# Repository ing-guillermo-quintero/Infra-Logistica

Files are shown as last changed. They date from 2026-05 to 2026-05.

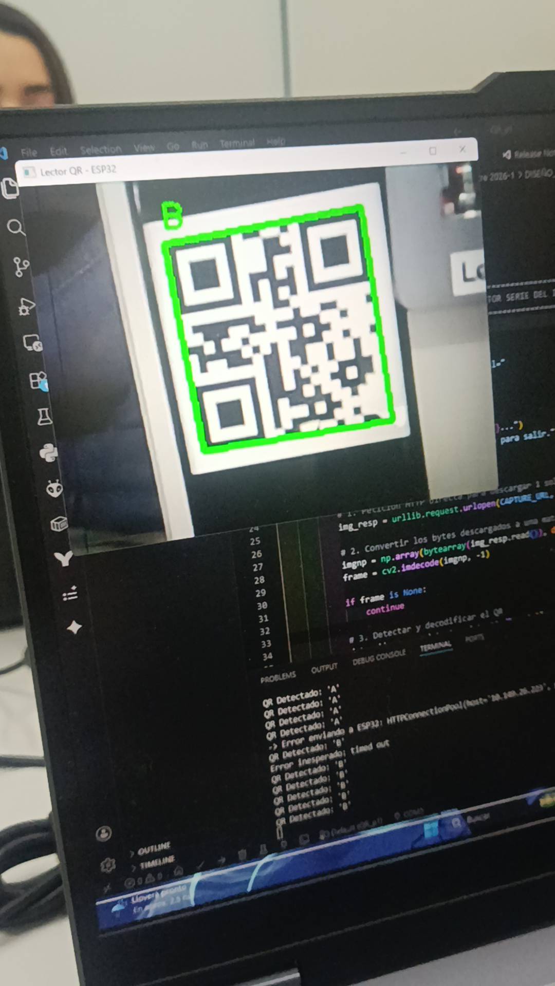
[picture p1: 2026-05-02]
Pruebas_unitarias_Sistema_Lectura_QR/IMG_1.jpg

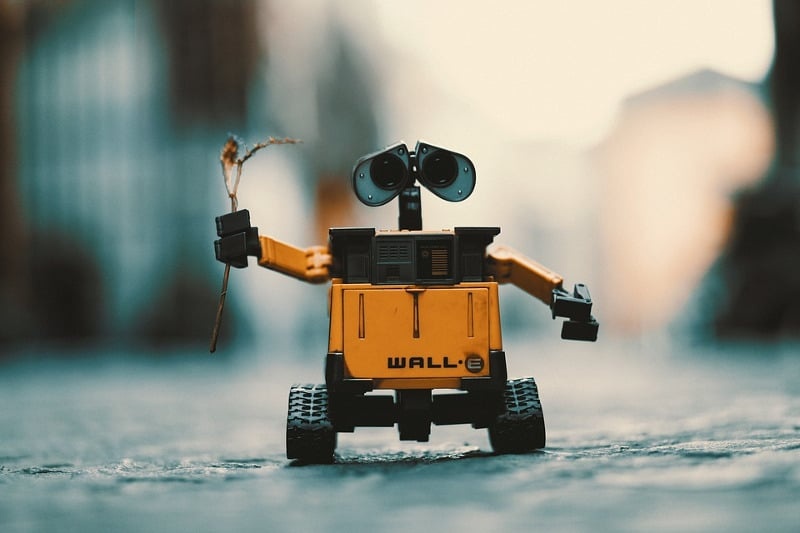
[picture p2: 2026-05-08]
Sistema_Lectura_QR/Lector_QR_V2/imagenes/wall-e.jpg

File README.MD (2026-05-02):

# 📦 Proyecto de Infraestructura y Logística

## 📖 Descripción General
Este repositorio contiene la documentación técnica, diseños mecánicos, planos generales y ruteo electrónico de un sistema de infraestructura logística automatizada.

El proyecto integra componentes mecánicos (estructura y banda transportadora), diseño eléctrico-electrónico y pruebas del sistema de lectura QR, permitiendo la identificación y transporte eficiente de elementos dentro del sistema.

---

## 🗂️ Estructura del Proyecto
.
├── CADs/
│ ├── Infraestructura.STEP
│ └── Banda_transportadora.STEP
│
├── Diseño_Plano_General/
│ └── (Planos generales del sistema)
│
├── Firmware_Infraestructura/
│
├── Pruebas_unitarias_Sistema_Lectura_QR/
│
├── Ruteo_eléctrico-electrónico/
│ └── (Archivo Proteus - conexiones electrónicas)
│
└── Sistema_Lectura_QR/

---

## 📁 Descripción de Carpetas

### 🔧 CADs/
Contiene los modelos 3D del sistema en formato `.STEP`, fundamentales para el diseño mecánico:

- **Infraestructura.STEP**  
  Representa la estructura completa del sistema logístico.

- **Banda_transportadora.STEP**  
  Modelo detallado de la banda transportadora, incluyendo soportes y sistema de desplazamiento.

Estos archivos permiten:
- Visualización tridimensional
- Validación dimensional
- Preparación para fabricación

---

### 📐 Diseño_Plano_General/
Incluye los planos generales del sistema, donde se define:

- Distribución de la infraestructura
- Ubicación de los módulos
- Relación entre componentes mecánicos

Sirve como referencia principal para el montaje físico del sistema.

---

### ⚙️ Firmware_Infraestructura/
Contiene el desarrollo del firmware encargado del control del sistema:

- Lógica de operación
- Control de actuadores
- Lectura de sensores
- Integración con el sistema de lectura QR

---

### 🧪 Pruebas_unitarias_Sistema_Lectura_QR/
Incluye pruebas orientadas a validar el funcionamiento del sistema de lectura QR:

- Precisión de lectura
- Tiempo de respuesta
- Integración con el sistema general

---

### 🔌 Ruteo_eléctrico-electrónico/
Contiene el diseño electrónico del sistema:

- Archivo de simulación en **Proteus**
- Conexiones del controlador
- Integración de sensores

Permite:
- Simulación del circuito
- Verificación de conexiones
- Validación del diseño electrónico

---

### 📡 Sistema_Lectura_QR/
Módulo encargado de la lectura e interpretación de códigos QR:

- Captura de datos
- Procesamiento de información
- Comunicación con el sistema principal

---

## 🧩 Componentes del Sistema

- Estructura mecánica modular
- Banda transportadora
- Sensores electrónicos
- Controlador principal
- Sistema de lectura QR

---

## 🎯 Objetivo del Proyecto

Desarrollar un sistema automatizado de logística que permita:

- Transporte eficiente de elementos
- Identificación mediante códigos QR
- Integración mecánica y electrónica
- Escalabilidad del sistema

---

## 🛠️ Herramientas Utilizadas

- Software CAD (archivos `.STEP`)
- Proteus (simulación electrónica)
- Sistemas embebidos (controlador)
- Herramientas de desarrollo de firmware

---

## 📌 Notas

- Los archivos `.STEP` pueden visualizarse en herramientas como SolidWorks, Fusion 360 o FreeCAD.
- El archivo de Proteus requiere el entorno instalado para su simulación.
- Este repositorio está orientado tanto a documentación técnica como a desarrollo del sistema.

---

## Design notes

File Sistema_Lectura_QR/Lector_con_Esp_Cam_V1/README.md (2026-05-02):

# Sistema de Visión y Detección QR con ESP32

Este proyecto contiene un script en Python (`Prueba1Webservice.py`) que actúa como cliente para un módulo ESP32 equipado con cámara. El sistema captura imágenes enviadas por el ESP32, procesa las imágenes para detectar códigos QR y envía la información decodificada de vuelta al microcontrolador.

La arquitectura está basada en un modelo **Cliente-Servidor** a través de red local (Wi-Fi), distribuido en dos componentes principales:

1. **Servidor (Edge Device - ESP32):**
   - El ESP32 actúa como un servidor web HTTP.
   - **Cámara:** Se encarga de capturar el entorno de manera continua.
   - **Endpoint `/capture`:** Proveedor de imágenes. Al hacer una petición GET, responde con el frame actual de la cámara (foto en formato binario/JPEG).
   - **Endpoint `/serial?val=<datos>`:** Receptor de comandos. Permite recibir cadenas de texto (en este caso, la información del QR) y procesarlas o mostrarlas por el monitor serie del microcontrolador.

2. **Cliente (Procesamiento de Visión - PC con Python):**
   - El script de Python realiza el procesamiento pesado que el ESP32 no puede o le costaría mucho hacer (Computer Vision).
   - Realiza _polling_ constante (peticiones HTTP directas) al endpoint `/capture` para simular un stream de video en tiempo real.
   - Decodifica la imagen utilizando `numpy` y `OpenCV`.
   - Utiliza `cv2.QRCodeDetector()` para analizar la imagen y buscar códigos QR.
   - Si detecta un código QR, envía el dato obtenido de regreso al ESP32 a través del endpoint `/serial`.

## Flujo de Funcionamiento del Código (`Prueba1Webservice.py`)

1. **Configuración y Conexión:**
   Se define la dirección IP del ESP32 (`ESP32_IP = "192.168.2.98"`) en la red local. A partir de ella se construyen las URLs para la captura de imágenes (`CAPTURE_URL`) y el envío de datos (`SERIAL_URL`).

2. **Bucle de Captura:**
   Entra en un ciclo infinito `while True` donde:
   - Se solicita la imagen al ESP32 mediante `urllib.request.urlopen`.
   - Los bytes recibidos se transforman en un arreglo (array) de `numpy`.
   - Se decodifica la imagen a un formato matricial (frame) compatible con OpenCV (`cv2.imdecode`).

3. **Detección y Decodificación del QR:**
   - El detector analiza el frame. Si encuentra un código QR, extrae las coordenadas (`bbox`) y la información en texto (`data`).
   - El código dibuja un recuadro verde alrededor del QR detectado utilizando `cv2.polylines`.

4. **Retorno de Información (Feedback) al ESP32:**
   - Se implementa una lógica de anti-spam (temporizador de 2 segundos mediante `time.time()`) para no sobrecargar de peticiones al ESP32 si el mismo QR permanece frente a la cámara.
   - Si hay una nueva lectura (o pasaron más de 2 segundos), la información es mostrada en la terminal local y enviada de vuelta al ESP32 utilizando la librería `requests` (`requests.get(SERIAL_URL + data)`).

5. **Visualización en PC:**
   - Para mejorar la visibilidad (dado que la resolución base parece ser baja, por ejemplo, 240p), el frame es redimensionado (`cv2.resize` a 640x480).
   - El flujo de video modificado (con los recuadros verdes y el texto) se muestra en una ventana interactiva (`cv2.imshow`).
   - El bucle puede detenerse en cualquier momento presionando la tecla **`q`**.

## Requisitos y Dependencias

Para ejecutar este script, es necesario contar con Python instalado y las siguientes librerías:

- `opencv-python` (cv2)
- `numpy`
- `requests`
- `urllib` (Librería estándar de Python)
- `time` (Librería estándar de Python)

Para instalar las dependencias externas (si no están instaladas), puedes ejecutar:

```bash
pip install opencv-python numpy requests
```

## Instrucciones de Uso

1. Cargar el firmware correspondiente en el ESP32 que levante el servidor web de la cámara y los endpoints (`/capture`, `/serial`).
2. Abrir el Monitor Serie del IDE de Arduino (u otro de preferencia) para observar la dirección IP asignada al ESP32.
3. Modificar la variable `ESP32_IP` en la **línea 10** del archivo `Prueba1Webservice.py` con la IP obtenida.
4. Ejecutar el script:
   ```bash
   python Prueba1Webservice.py
   ```
5. Colocar un código QR frente a la cámara del ESP32. Se podrá ver en la ventana del PC el recuadro de reconocimiento y el ESP32 recibirá la información.
6. Presionar la tecla `q` en la ventana del video para cerrar el programa.

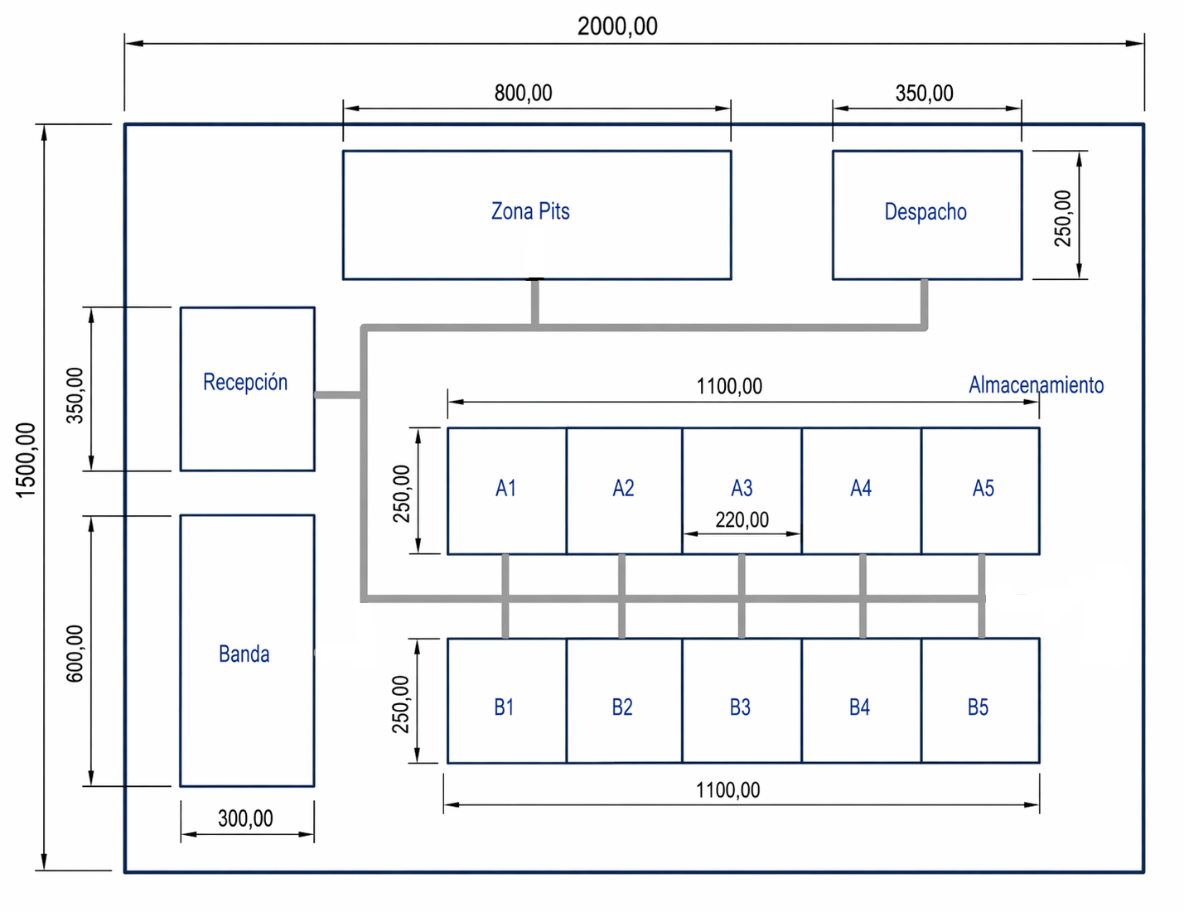
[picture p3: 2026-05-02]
Diseño_Plano_General/Diseno.png

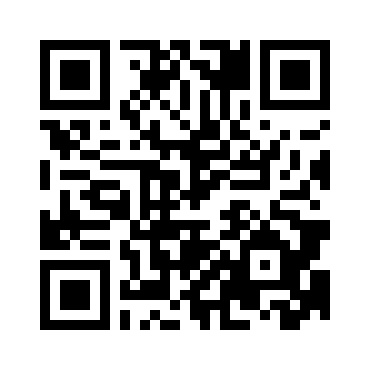
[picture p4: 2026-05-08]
Sistema_Lectura_QR/Lector_QR_V2/codigos_qr/QR_wall-e.png

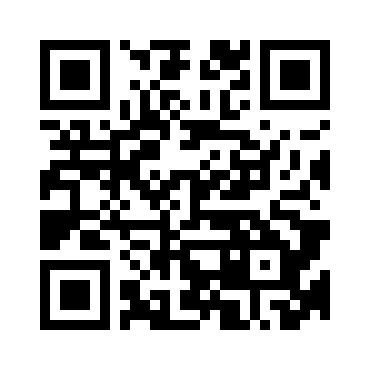
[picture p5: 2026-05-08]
Sistema_Lectura_QR/Lector_QR_V2/codigos_qr/QR_rosas.png

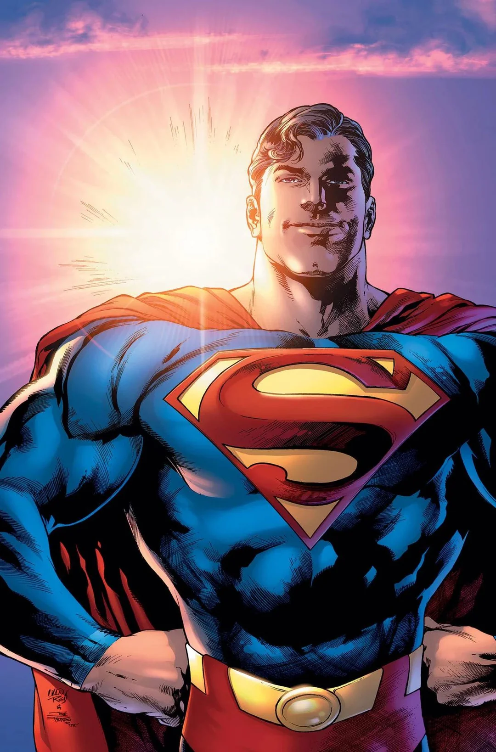
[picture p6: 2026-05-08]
Sistema_Lectura_QR/Lector_QR_V2/imagenes/superman.webp

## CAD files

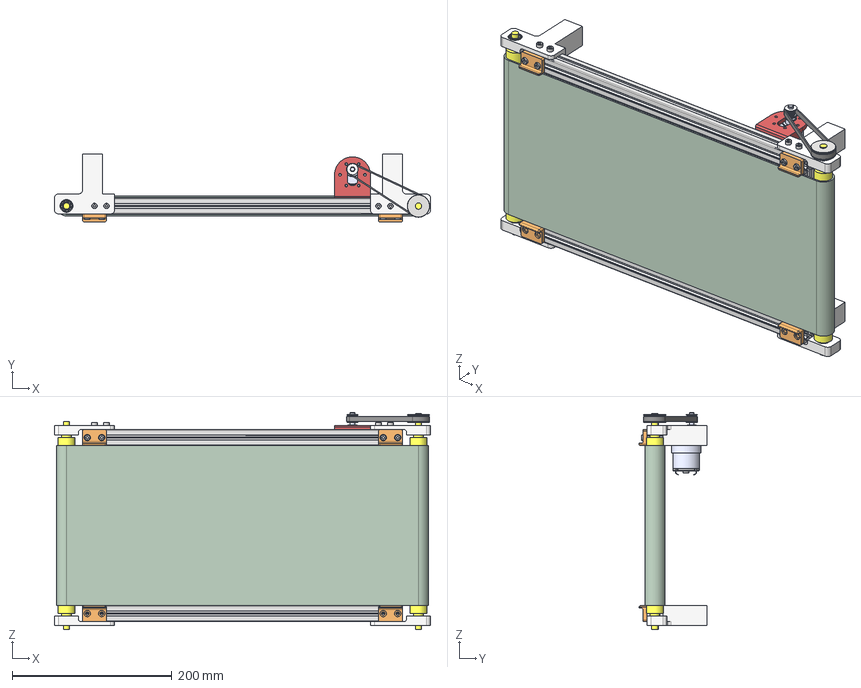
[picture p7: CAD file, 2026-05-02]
CADs/Banda_transportadora.stp
470.0 x 85.2 x 271.5 mm
tslot-20x20-1
tslot-20x20-1_MIR
tslot-20x20-2 x 3
SNSD20x20 x 3
SNSD20x20_MIR x 3
MM-JGB37 v4_MIR_MIR
JGB37-520_MIR_MIR
lato
cilindro_01
piastra_laterale_cilindro
GT2 16 Teeth Free Pulley
GT2 Timing Pulley T40 small
%3% BS 290 - SKF 618/8 x 6
piastra_laterale_cilindro_MIR
cilindro_01_MIR
piastra_laterale_cilindro_MIR1
piastra_laterale_cilindro_MIR_MIR
cinghia
nastro
blocco_nastro
blocco_nastro_MIR
blocco_nastro_MIR1
blocco_nastro_MIR_MIR
AS 1420 - 1973 - M4 x 8 x 8
AS 1420 - 1973 - M4 x 20 x 2

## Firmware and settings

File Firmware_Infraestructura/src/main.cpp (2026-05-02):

#include <Arduino.h>
#include <WiFi.h>
#include <PubSubClient.h>

// ==========================================
// CONFIGURACIÓN WIFI Y MQTT
// ==========================================
const char* ssid = "TU_RED_WIFI";
const char* password = "TU_PASSWORD";
const char* mqtt_server = "IP_DE_TU_BROKER";
const int mqtt_port = 1883;

WiFiClient espClient;
PubSubClient client(espClient);

// Mutex para proteger la librería MQTT entre los dos núcleos
SemaphoreHandle_t mqttMutex;

// ==========================================
// DEFINICIÓN DE PINES (ESP32-S3)
// ==========================================
// Zona de Recolección - Motor
const int PIN_ENA = 4;
const int PIN_IN1 = 5;
const int PIN_IN2 = 6;

// Zona de Recolección - Sensores IR
const int PIN_SENSOR_IR1 = 7;
const int PIN_SENSOR_IR2 = 8;

// Zona de Almacenamiento - Registro de Desplazamiento
const int LATCH_PIN = 9;
const int CLOCK_PIN = 10;
const int DATA_PIN  = 11;

// Zona de Despacho
const int PIN_SENSOR_DESPACHO = 12;

// ==========================================
// VARIABLES DE ESTADO
// ==========================================
enum EstadoBanda { BANDA_CORRIENDO, ESPERANDO_PARADA, CAJA_LISTA };
EstadoBanda estadoActualBanda = BANDA_CORRIENDO;

unsigned long tiempoDeteccionIR1 = 0;
const unsigned long TIEMPO_ESPERA_PARADA = 2000;
unsigned long ultimoEnvioSensores = 0;
const unsigned long INTERVALO_ENVIO_SENSORES = 1000;
int estadoAnteriorDespacho = -1;

// ==========================================
// PROTOTIPOS DE FUNCIONES (Requerido en C++/PlatformIO)
// ==========================================
void setup_wifi();
void reconnect();
void arrancarBanda();
void detenerBanda();
uint16_t leerRegistroDesplazamiento();
void TareaSensoresYRed(void *pvParameters);
void TareaRecepcionYDespacho(void *pvParameters);

// ==========================================
// FUNCIONES DE RED
// ==========================================
void setup_wifi() {
  vTaskDelay(pdMS_TO_TICKS(10));
  Serial.println("\nConectando a WiFi...");
  WiFi.begin(ssid, password);
  while (WiFi.status() != WL_CONNECTED) {
    vTaskDelay(pdMS_TO_TICKS(500));
    Serial.print(".");
  }
  Serial.println("\nWiFi conectado.");
}

void reconnect() {
  while (!client.connected() && WiFi.status() == WL_CONNECTED) {
    Serial.print("Intentando conexión MQTT...");
    if (client.connect("ESP32_S3_Almacen")) {
      Serial.println("Conectado al broker");
    } else {
      Serial.print("Fallo, rc=");
      Serial.print(client.state());
      Serial.println(" reintentando en 5 segundos");
      vTaskDelay(pdMS_TO_TICKS(5000));
    }
  }
}

// ==========================================
// FUNCIONES DE CONTROL FÍSICO
// ==========================================
void arrancarBanda() {
  digitalWrite(PIN_IN1, HIGH);
  digitalWrite(PIN_IN2, LOW);
  analogWrite(PIN_ENA, 200);
}

void detenerBanda() {
  digitalWrite(PIN_IN1, LOW);
  digitalWrite(PIN_IN2, LOW);
  analogWrite(PIN_ENA, 0);
}

uint16_t leerRegistroDesplazamiento() {
  digitalWrite(LATCH_PIN, LOW);
  delayMicroseconds(5);
  digitalWrite(LATCH_PIN, HIGH);
  
  uint16_t valores = 0;
  for (int i = 0; i < 16; i++) {
    int bitLeido = digitalRead(DATA_PIN);
    valores |= (bitLeido << (15 - i));
    digitalWrite(CLOCK_PIN, HIGH);
    delayMicroseconds(5);
    digitalWrite(CLOCK_PIN, LOW);
  }
  return valores;
}

// ==========================================
// TAREAS DE LOS NÚCLEOS (FreeRTOS)
// ==========================================

// --- NÚCLEO 0: Sensores de Almacenamiento y Red MQTT ---
void TareaSensoresYRed(void *pvParameters) {
  setup_wifi();
  client.setServer(mqtt_server, mqtt_port);

  for (;;) {
    if (xSemaphoreTake(mqttMutex, portMAX_DELAY) == pdTRUE) {
      if (!client.connected()) {
        reconnect();
      }
      client.loop();
      xSemaphoreGive(mqttMutex);
    }

    if (millis() - ultimoEnvioSensores >= INTERVALO_ENVIO_SENSORES) {
      ultimoEnvioSensores = millis();
      uint16_t sensoresAlmacen = leerRegistroDesplazamiento();
      
      String payload = "{";
      payload += "\"FilaA\": [";
      for(int i=0; i<5; i++) {
        payload += String(bitRead(sensoresAlmacen, i));
        if(i < 4) payload += ",";
      }
      payload += "], \"FilaB\": [";
      for(int i=0; i<5; i++) {
        payload += String(bitRead(sensoresAlmacen, i + 8));
        if(i < 4) payload += ",";
      }
      payload += "]}";
      
      if (xSemaphoreTake(mqttMutex, portMAX_DELAY) == pdTRUE) {
        client.publish("almacen/almacenamiento/celdas", payload.c_str());
        xSemaphoreGive(mqttMutex);
      }
    }
    vTaskDelay(pdMS_TO_TICKS(10)); 
  }
}

// --- NÚCLEO 1: Recepción (Banda) y Despacho ---
void TareaRecepcionYDespacho(void *pvParameters) {
  arrancarBanda();

  for (;;) {
    bool deteccionIR1 = (digitalRead(PIN_SENSOR_IR1) == LOW);
    bool deteccionIR2 = (digitalRead(PIN_SENSOR_IR2) == LOW);

    switch (estadoActualBanda) {
      case BANDA_CORRIENDO:
        if (deteccionIR1) {
          tiempoDeteccionIR1 = millis();
          estadoActualBanda = ESPERANDO_PARADA;
        }
        break;

      case ESPERANDO_PARADA:
        if (millis() - tiempoDeteccionIR1 >= TIEMPO_ESPERA_PARADA) {
          detenerBanda();
          if (xSemaphoreTake(mqttMutex, portMAX_DELAY) == pdTRUE) {
            client.publish("almacen/recoleccion/estado", "CAJA_EN_ESPERA");
            xSemaphoreGive(mqttMutex);
          }
          estadoActualBanda = CAJA_LISTA;
        }
        break;

      case CAJA_LISTA:
        if (!deteccionIR2) { 
          arrancarBanda();
          if (xSemaphoreTake(mqttMutex, portMAX_DELAY) == pdTRUE) {
            client.publish("almacen/recoleccion/estado", "CAJA_RECOGIDA_BANDA_ACTIVA");
            xSemaphoreGive(mqttMutex);
          }
          estadoActualBanda = BANDA_CORRIENDO;
        }
        break;
    }

    int estadoActualDespacho = digitalRead(PIN_SENSOR_DESPACHO);
    if (estadoActualDespacho != estadoAnteriorDespacho) {
      if (xSemaphoreTake(mqttMutex, portMAX_DELAY) == pdTRUE) {
        if (estadoActualDespacho == LOW) {
          client.publish("almacen/despacho/estado", "CAJA_LISTA_PARA_DESPACHO");
        } else {
          client.publish("almacen/despacho/estado", "CELDA_DESPACHO_VACIA");
        }
        xSemaphoreGive(mqttMutex);
      }
      estadoAnteriorDespacho = estadoActualDespacho;
    }

    vTaskDelay(pdMS_TO_TICKS(10)); 
  }
}

// ==========================================
// CONFIGURACIÓN INICIAL (SETUP)
// ==========================================
void setup() {
  Serial.begin(115200);
  
  pinMode(PIN_ENA, OUTPUT);
  pinMode(PIN_IN1, OUTPUT);
  pinMode(PIN_IN2, OUTPUT);
  pinMode(PIN_SENSOR_IR1, INPUT_PULLUP);
  pinMode(PIN_SENSOR_IR2, INPUT_PULLUP);
  pinMode(LATCH_PIN, OUTPUT);
  pinMode(CLOCK_PIN, OUTPUT);
  pinMode(DATA_PIN, INPUT);
  pinMode(PIN_SENSOR_DESPACHO, INPUT_PULLUP);

  mqttMutex = xSemaphoreCreateMutex();
  if (mqttMutex == NULL) {
    Serial.println("Error al crear el Mutex");
    while(1);
  }

  xTaskCreatePinnedToCore(
    TareaSensoresYRed, "TareaRed", 8192, NULL, 1, NULL, 0
  );

  xTaskCreatePinnedToCore(
    TareaRecepcionYDespacho, "TareaMotores", 4096, NULL, 1, NULL, 1
  );

  vTaskDelete(NULL); 
}

void loop() {
  // Vacío intencionalmente (Controlado por FreeRTOS)
}

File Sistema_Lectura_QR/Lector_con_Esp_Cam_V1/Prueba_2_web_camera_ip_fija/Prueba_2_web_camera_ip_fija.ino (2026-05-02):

#include "esp_camera.h"
#include <WiFi.h>
#include "esp_http_server.h"

// ==========================================
// 1. Configuración de Red
// ==========================================
const char* ssid = "ESP_CAM_RED";
const char* password = "";

// --- NUEVO: Configuración de IP Fija ---
IPAddress local_IP(192, 168, 2, 98);
IPAddress gateway(192, 168, 2, 1);   // Asegúrate de que esta sea la IP de tu router
IPAddress subnet(255, 255, 255, 0);
IPAddress primaryDNS(8, 8, 8, 8);    // Opcional
IPAddress secondaryDNS(8, 8, 4, 4);  // Opcional
// ---------------------------------------

// Pines AI-Thinker
#define PWDN_GPIO_NUM     32
#define RESET_GPIO_NUM    -1
#define XCLK_GPIO_NUM      0
#define SIOD_GPIO_NUM     26
#define SIOC_GPIO_NUM     27
#define Y9_GPIO_NUM       35
#define Y8_GPIO_NUM       34
#define Y7_GPIO_NUM       39
#define Y6_GPIO_NUM       36
#define Y5_GPIO_NUM       21
#define Y4_GPIO_NUM       19
#define Y3_GPIO_NUM       18
#define Y2_GPIO_NUM        5
#define VSYNC_GPIO_NUM    25
#define HREF_GPIO_NUM     23
#define PCLK_GPIO_NUM     22

httpd_handle_t camera_httpd = NULL;

// ==========================================
// 2. Handlers del Servidor
// ==========================================

// Handler para enviar una sola FOTO (No streaming)
static esp_err_t capture_handler(httpd_req_t *req) {
  camera_fb_t * fb = esp_camera_fb_get();
  if (!fb) {
    Serial.println("Fallo al capturar la imagen");
    httpd_resp_send_500(req);
    return ESP_FAIL;
  }

  httpd_resp_set_type(req, "image/jpeg");
  esp_err_t res = httpd_resp_send(req, (const char *)fb->buf, fb->len);
  
  esp_camera_fb_return(fb); // Liberar memoria inmediatamente
  return res;
}

// Handler para recibir la letra del QR
static esp_err_t serial_handler(httpd_req_t *req) {
  char buf[64];
  if (httpd_req_get_url_query_str(req, buf, sizeof(buf)) == ESP_OK) {
    char value[32];
    if (httpd_query_key_value(buf, "val", value, sizeof(value)) == ESP_OK) {
      Serial.print("QR Detectado: ");
      Serial.println(value);
    }
  }
  
  // Agregar cabeceras CORS para evitar bloqueos
  httpd_resp_set_hdr(req, "Access-Control-Allow-Origin", "*");
  httpd_resp_send(req, "OK", 2);
  return ESP_OK;
}

// Mensaje básico si entras por error a la raíz
static esp_err_t index_handler(httpd_req_t *req) {
  httpd_resp_set_type(req, "text/html");
  const char* resp = "<h1>ESP32 Activa</h1><p>Usa Python para procesar la imagen desde /capture</p>";
  return httpd_resp_send(req, resp, strlen(resp));
}

void startCameraServer(){
  httpd_config_t config = HTTPD_DEFAULT_CONFIG();
  config.server_port = 80;

  httpd_uri_t index_uri = { .uri = "/", .method = HTTP_GET, .handler = index_handler, .user_ctx = NULL };
  httpd_uri_t capture_uri = { .uri = "/capture", .method = HTTP_GET, .handler = capture_handler, .user_ctx = NULL };
  httpd_uri_t serial_uri = { .uri = "/serial", .method = HTTP_GET, .handler = serial_handler, .user_ctx = NULL };
  
  if (httpd_start(&camera_httpd, &config) == ESP_OK) {
    httpd_register_uri_handler(camera_httpd, &index_uri);
    httpd_register_uri_handler(camera_httpd, &capture_uri);
    httpd_register_uri_handler(camera_httpd, &serial_uri);
  }
}

// ==========================================
// 3. Setup y Loop
// ==========================================
void setup() {
  Serial.begin(115200);
  Serial.println();

  camera_config_t config;
  config.ledc_channel = LEDC_CHANNEL_0;
  config.ledc_timer = LEDC_TIMER_0;
  config.pin_d0 = Y2_GPIO_NUM; config.pin_d1 = Y3_GPIO_NUM; config.pin_d2 = Y4_GPIO_NUM;
  config.pin_d3 = Y5_GPIO_NUM; config.pin_d4 = Y6_GPIO_NUM; config.pin_d5 = Y7_GPIO_NUM;
  config.pin_d6 = Y8_GPIO_NUM; config.pin_d7 = Y9_GPIO_NUM; config.pin_xclk = XCLK_GPIO_NUM;
  config.pin_pclk = PCLK_GPIO_NUM; config.pin_vsync = VSYNC_GPIO_NUM; config.pin_href = HREF_GPIO_NUM;
  config.pin_sccb_sda = SIOD_GPIO_NUM; config.pin_sccb_scl = SIOC_GPIO_NUM;
  config.pin_pwdn = PWDN_GPIO_NUM; config.pin_reset = RESET_GPIO_NUM;
  config.xclk_freq_hz = 20000000;
  config.pixel_format = PIXFORMAT_JPEG; 
  
  // Resolución baja (240p) para que las peticiones por WiFi vuelen
  config.frame_size = FRAMESIZE_QVGA;
  config.jpeg_quality = 12;
  config.fb_count = 1;

  esp_err_t err = esp_camera_init(&config);
  if (err != ESP_OK) {
    Serial.printf("Fallo de cámara: 0x%x", err);
    return;
  }

  // Subir contraste para mejor lectura B/N de los QR
  sensor_t * s = esp_camera_sensor_get();
  s->set_contrast(s, 2);

  // --- NUEVO: Aplicar configuración de IP Fija ---
  if (!WiFi.config(local_IP, gateway, subnet, primaryDNS, secondaryDNS)) {
    Serial.println("Fallo al configurar IP estática");
  }
  // -----------------------------------------------

  WiFi.begin(ssid, password);
  while (WiFi.status() != WL_CONNECTED) { delay(500); Serial.print("."); }
  
  Serial.println("\nWiFi conectado");
  startCameraServer();
  Serial.print("IP de la ESP32: ");
  Serial.println(WiFi.localIP());
}

void loop() {
  delay(10000);
}

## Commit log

2026-05-02 Infra-Logistica_Diseño_Detallado
    [Banda_transportadora.stp]
2026-05-02 Agregar Sistema de Lectura de QR como carpeta y no como sub-repositorio
2026-05-08 Agregue el diseño modificado del sticker
2026-05-08 Agregue el nuevo codigo de lectura de QR con informacion mas detallada, pero falta confirmar en otros subsistemas antes de implementarle la espcam
2026-05-15 modficacion de ruteo electronico / división de pcbs y modificacionn del cad general de infraestructura y del diseño sticker
